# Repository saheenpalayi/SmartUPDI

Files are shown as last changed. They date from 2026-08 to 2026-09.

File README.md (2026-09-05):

# SmartUPDI

SmartUPDI is an open hardware UPDI programmer and USART adapter for modern AVR microcontrollers. It can switch between programming mode and serial communication with the target device, making it useful for both firmware development and serial debugging.

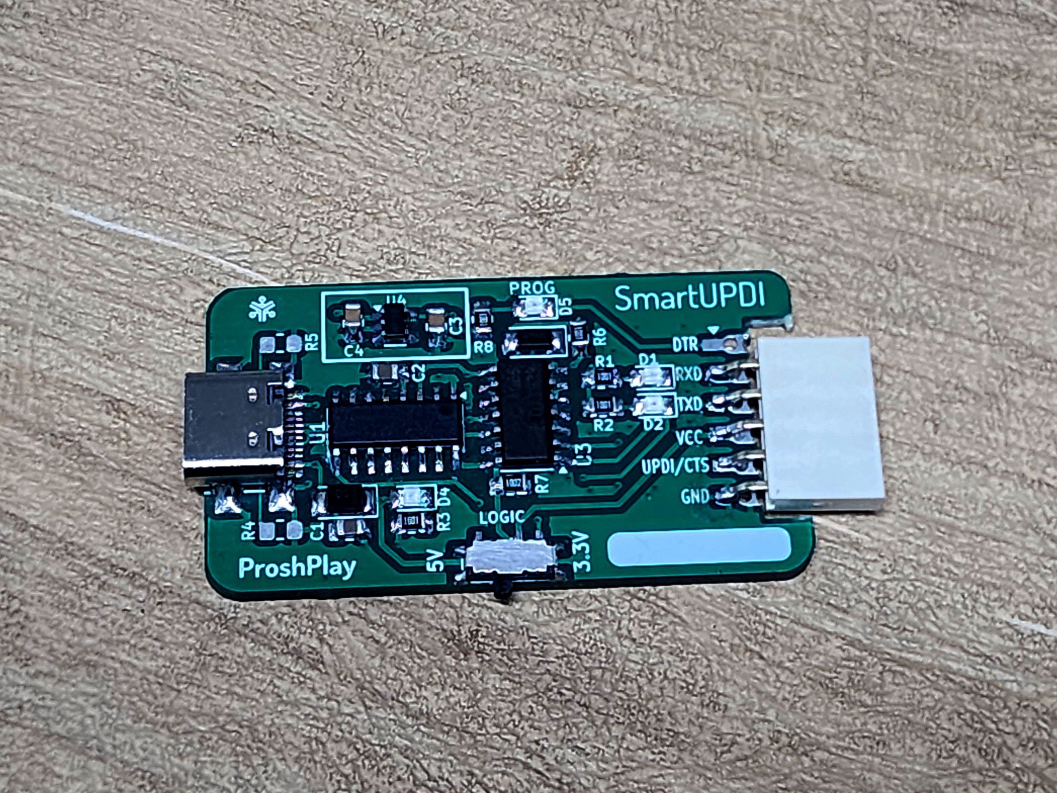
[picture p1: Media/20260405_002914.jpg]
SmartUPDI assembled board


## Project Report

This repository contains the design files and manufacturing outputs for SmartUPDI. It includes a modified revision of the original Version 1 design. Version 1 was assembled and tested as a working prototype, and the modified revision addresses the known Version 1 issues.

### Features

- UPDI programming for supported AVR microcontrollers
- Switchable connection to the target device's USART interface
- One tool for programming and serial communication during development
- Four to five alternative output connector options for different target hardware setups
- KiCad schematic and PCB source files included
- Gerber manufacturing files included

### Modified Revision

The modified version in this repository improves on the original Version 1 hardware. The previously reported LED issues and macOS automatic switching issue have been resolved in this revision.

The board also provides four to five different output connector options. Users can select the connector arrangement that best suits their target hardware and solder the required connector option during assembly.

### Compatibility And Testing

SmartUPDI has been tested with:

- Linux
- Windows
- Arduino projects using the latest MegaTinyCore
- ATtiny AVR 1-series devices
- AVR128DB-series devices, including AVR128DB-family targets

The original Version 1 prototype worked correctly on Linux and Windows, but had LED issues and problems with automatic switching on macOS. These issues have been addressed in the modified revision contained in this repository.

### Original Version 1.0

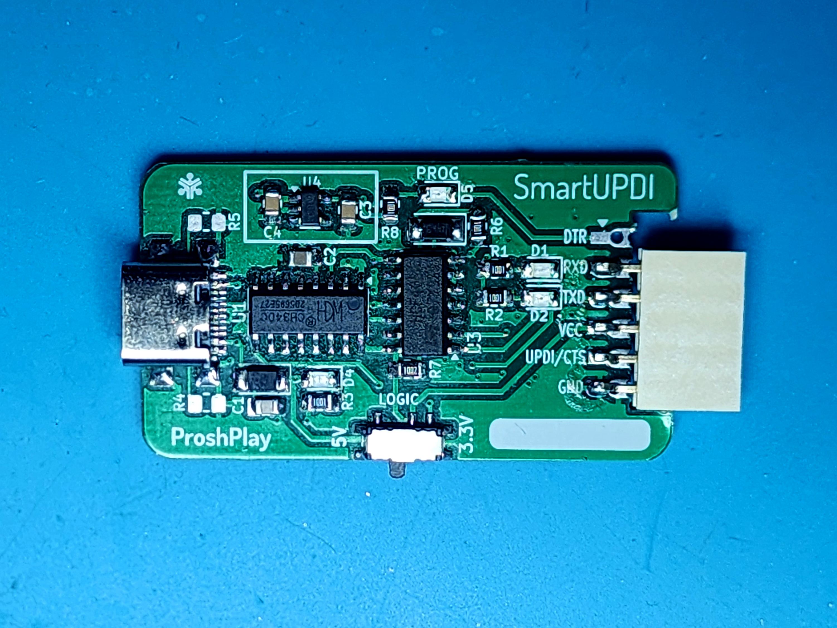
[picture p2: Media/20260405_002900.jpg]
SmartUPDI Version 1.0


## Repository Contents

- `Design Files/` - KiCad project, schematic, PCB layout, and project settings
- `Gerber Files/` - fabrication outputs for manufacturing the PCB
- `Media/` - project and assembled-board photographs

## Building Your Own

Anyone may manufacture SmartUPDI for personal use, education, experimentation, or integration into their own projects. Review the schematic, PCB layout, and Gerber files before fabrication, and verify the board against your own target hardware and power requirements.

## Usage And Distribution Policy

You may build, modify, and use SmartUPDI as needed. Reselling the SmartUPDI project, assembled boards, or kits based on this design is prohibited without the author's permission.

This project is provided as-is. Hardware assembly and use are performed at your own risk. Always confirm voltage levels, wiring, and target-device connections before programming.

## License

See [LICENSE](LICENSE) for the license currently included with this repository. The author's intended project policy is that anyone may build and use SmartUPDI, but resale is prohibited. Because the included CC0 text permits commercial redistribution, the license file should be replaced with a license that explicitly prohibits resale if that restriction must be enforceable.

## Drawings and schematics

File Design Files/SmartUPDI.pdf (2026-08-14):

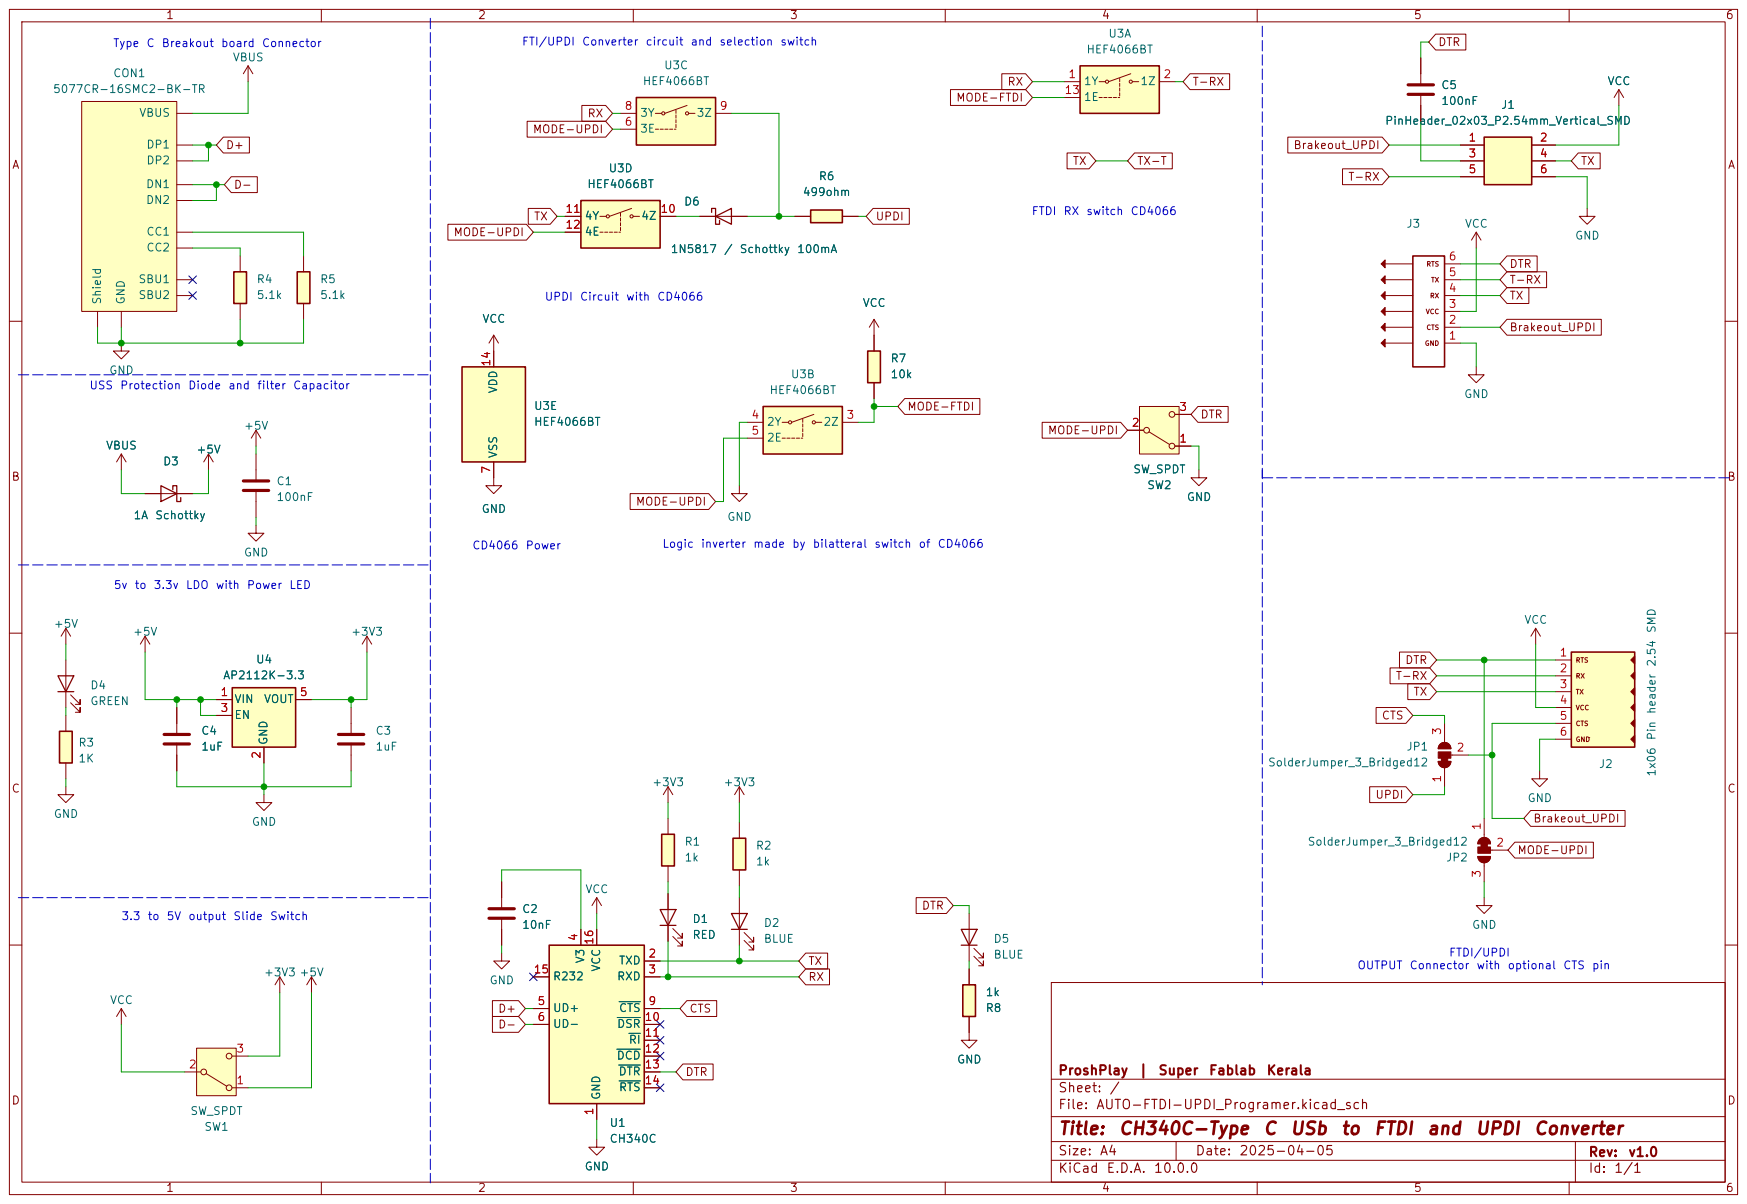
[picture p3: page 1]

Type C Breakout board Connector

FTI/UPDI Converter circuit and selection switch

TX RX MODE-FTDI

4 UD+ 5 UD- 6 CTS 9 DSR 10 RI 11 DCD 12 DTR 13 RTS 14 R232 15 VCC 16 U3D HEF4066BT4Z 10 4Y 11

FTDI RX switch CD4066 USS Protection Diode and filter Capacitor

Logic inverter made by bilatteral switch of CD4066

4 UD+ 5 UD- 6 CTS 9 DSR 10 RI 11 DCD 12 DTR 13 RTS 14 R232 15 VCC 16 U1CH340C

OUTPUT Connector with optional CTS pin

ProshPlay | Super Fablab Kerala
Sheet: /
D Date: 2025-04-05 KiCad E.D.A. 10.0.0
File: AUTO-FTDI-UPDI_Programer.kicad_sch
Title: CH340C-Type C USb to FTDI and UPDI Converter

Size: A4 | Rev: v1.0

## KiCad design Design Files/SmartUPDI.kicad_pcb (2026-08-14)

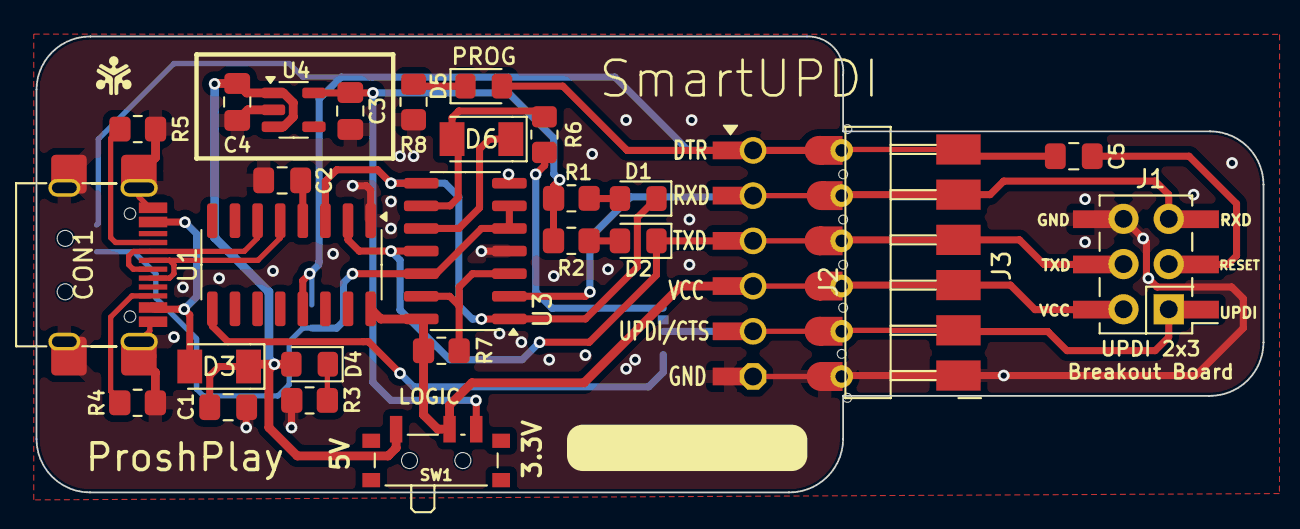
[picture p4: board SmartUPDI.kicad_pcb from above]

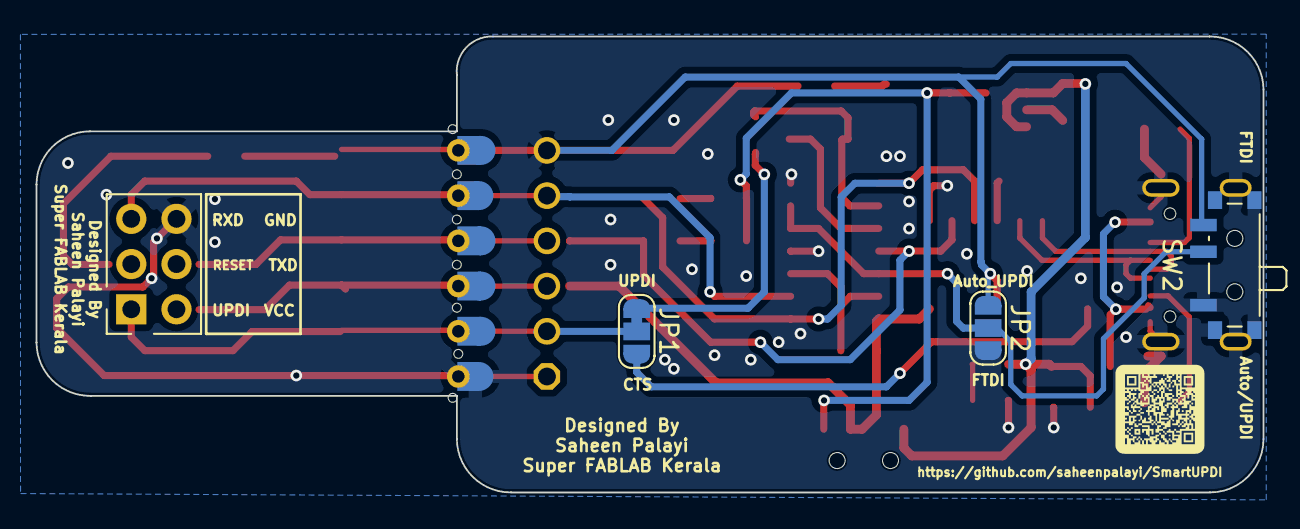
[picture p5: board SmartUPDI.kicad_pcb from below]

Board: 2 copper layers, 68.9 x 25.6 mm, 30 parts (3 on the bottom side), 25 nets.

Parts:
C1, C5: 100nF; C_0805_2012Metric_Pad1.18x1.45mm_HandSolder
C2: 10nF; C_0805_2012Metric_Pad1.18x1.45mm_HandSolder
C3, C4: 1uF; C_0805_2012Metric_Pad1.18x1.45mm_HandSolder
CON1: 5077CR-16SMC2-BK-TR; USB_C_Receptacle_G-Switch_GT-USB-7010ASV
D1: RED; LED_0805_2012Metric_Pad1.15x1.40mm_HandSolder
D2, D5: BLUE; LED_0805_2012Metric_Pad1.15x1.40mm_HandSolder
D3: 1A Schottky; Diode_Schottky_MiniSMA
D4: GREEN; LED_0805_2012Metric_Pad1.15x1.40mm_HandSolder
D6: 1N5817 / Schottky 100mA; Diode_Schottky_MiniSMA
J1: PinHeader_02x03_P2.54mm_Vertical_SMD
J2: 1x06 Pin header 2.54 SMD; PinSocket_1x06_P2.54mm_Horizontal_SMD
J3: Conn_PinHeader_FTDI_1x06_P2.54mm_Horizontal_SMD; PinHeader_1x06_P2.54mm_Horizontal_SMD
JP1, JP2: SolderJumper_3_Bridged12; SolderJumper-3_P1.3mm_Bridged12_RoundedPad1.0x1.5mm_NumberL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
R1, R2, R8: 1k; R_0805_2012Metric_Pad1.20x1.40mm_HandSolder
R3: 1K; R_0805_2012Metric_Pad1.20x1.40mm_HandSolder
R4, R5: 5.1k; R_0805_2012Metric_Pad1.20x1.40mm_HandSolder
R6: 499ohm; R_0805_2012Metric_Pad1.20x1.40mm_HandSolder
R7: 10k; R_0805_2012Metric_Pad1.20x1.40mm_HandSolder
SW1, SW2: SW_SPDT; SW_SPDT_PCM12
U1: CH340C; SOIC-16_3.9x9.9mm_P1.27mm
U3: HEF4066BT; SOIC-14_3.9x8.7mm_P1.27mm
U4: AP2112K-3.3; SOT-23-5

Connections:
+3V3: C3.1, R1.1, R2.1, SW1.3 (C), U4.5 (VOUT)
+5V: C1.1, C4.1, D3.1 (K), D4.2 (A), SW1.1 (A), U4.1 (VIN), U4.3 (EN)
Brakeout_UPDI: J1.1, J2.5, J3.2, JP1.2 (C)
CTS: JP1.3 (B), U1.9 (~CTS)
D+: CON1.A6 (DP1), CON1.B6 (DP2), U1.5 (UD+)
D-: CON1.A7 (DN1), CON1.B7 (DN2), U1.6 (UD-)
DTR: C5.1, D5.2 (A), J2.1, J3.6, JP2.1 (A), SW2.3 (C), U1.13 (~DTR)
GND: C1.2, C2.2, C3.2, C4.2, CON1.S1 (Shield), J1.6, J2.6, J3.1, JP2.3 (B), R3.2, R4.2, R5.2, R8.1, SW2.1 (A), U1.1 (GND), U3.4 (2Y), U3.7 (VSS), U4.2 (GND)
MODE-FTDI: R7.1, U3.3 (2Z), U3.13 (1E)
MODE-UPDI: JP2.2 (C), SW2.2 (B), U3.5 (2E), U3.6 (3E), U3.12 (4E)
unnamed: CON1.A5 (CC1), R5.1
unnamed: CON1.B5 (CC2), R4.1
unnamed: D1.2 (A), R1.2
unnamed: D2.2 (A), R2.2
unnamed: D4.1 (K), R3.1
unnamed: D5.1 (K), R8.2
unnamed: D6.2 (A), R6.1, U3.9 (3Z)
unnamed: D6.1 (K), U3.10 (4Z)
unnamed: C5.2, J1.3
unnamed: C2.1, U1.4 (V3)
RX: D1.1 (K), U1.3 (RXD), U3.1 (1Y), U3.8 (3Y)
T-RX: J1.5, J2.2, J3.5, U3.2 (1Z)
TX: D2.1 (K), J1.4, J2.3, J3.4, U1.2 (TXD), U3.11 (4Y)
UPDI: JP1.1 (A), R6.2
VCC: J1.2, J2.4, J3.3, R7.2, SW1.2 (B), U1.16 (VCC), U3.14 (VDD)
